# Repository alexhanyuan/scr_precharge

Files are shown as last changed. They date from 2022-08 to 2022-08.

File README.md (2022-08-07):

# scr_precharge
Controller for Solid State Tesla Coil power supply precharging with SCRs. I got tired of welding relays and didn't have the room for larger (>30A) contactors. I had a bunch of Semikron SKKT dual SCR modules, which were the same Semipack 1 style diode modules I was already using. So, using this precharge controller gets rid of the main relay as well as the precharge resistor and relay.

Eagle files for Semipack 1 gate driver boards are also included. These can be soldered up for modules with either gate configuration (GK GK or GK KG). The parts for the spade connectors that work with the Semipack 1 modules are:
https://www.digikey.com/en/products/detail/keystone-electronics/3544/303877

ST Microelectronics has a good app note on controlling SCRs and topologies:
https://www.st.com/resource/en/application_note/an4606-inrushcurrent-limiter-circuits-icl-with-triacs-and-thyristors-scr-and-controlled-bridge-design-tips-stmicroele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

The board comprises of a zero crossing detector, an ATTINY85 which generates the appropriate PWM gate signals, GDT outputs, and opto-isolated control inputs for precharge and run modes. There are two versions of the board, only difference being the type of GDT used, depending on the type of SCR configuration (dual or half SCR/diode modules).

The SCRs will need a gate resistor sized appropriately for the amount of current necessary to turn it on. I used 5.1 ohms on the Semipack 1 SKKT modules. The precharge board outputs must also be phased properly. Additionally, on 120VAC input, the hot line must be connected to pin 1 of X2 otherwise the zero crossing detector will not be able to detect any zero crossings. With 240VAC, both lines are hot so it will not matter.

Pick your opto of choice, then size the resistors according to the logic voltage. I used this with a UD3 so the signals were 24V.

If you have any questions or are looking for a couple of bare boards, feel free to shoot me a message! 

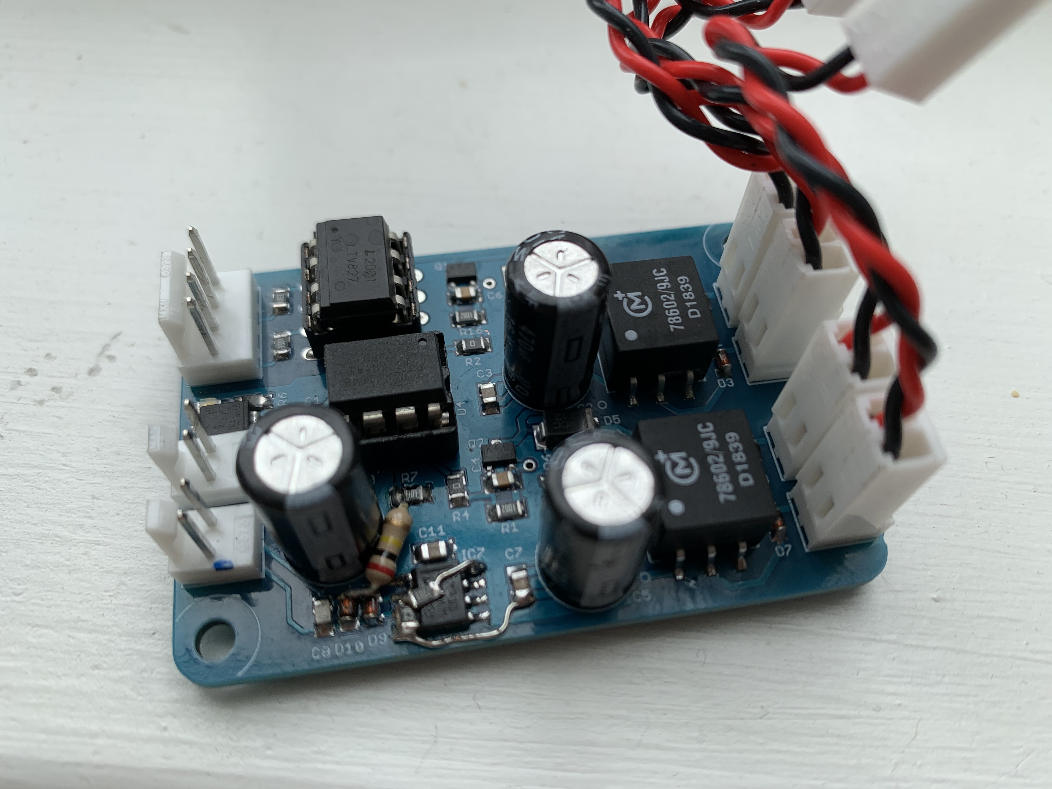
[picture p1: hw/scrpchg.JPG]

|:--:| 
| *Figure 1. Controller board. Note that this is was the original version and modifications needed to be made to the zero crossing detector. These changes are reflected in the latest board files.* |

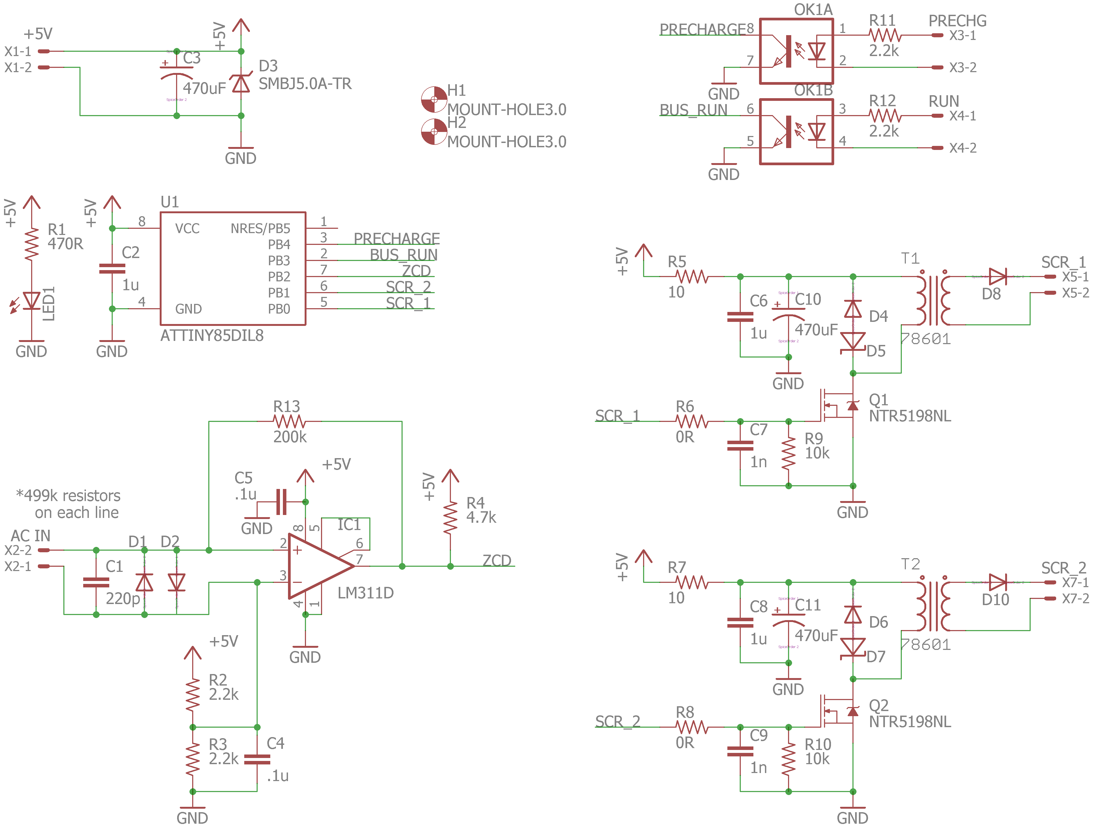
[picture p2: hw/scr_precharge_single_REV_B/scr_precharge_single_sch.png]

|:--:| 
| *Figure 2. Schematic of single output controller board.* |

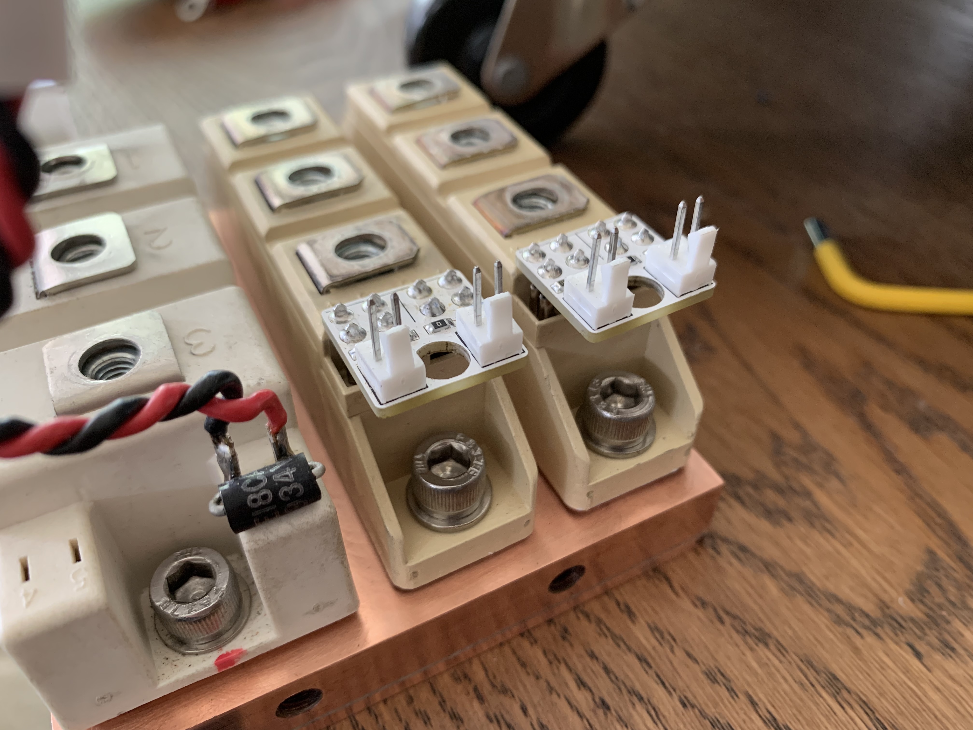
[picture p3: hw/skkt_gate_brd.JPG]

|:--:| 
| *Figure 3. Dual Semikron SCR modules with the gate boards.* |

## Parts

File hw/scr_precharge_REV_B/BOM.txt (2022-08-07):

Partlist

Exported from scr_precharge.sch at 8/6/2022 15:54

EAGLE Version 7.6.0 Copyright (c) 1988-2016 CadSoft

Assembly variant: 

Part     Value           Device             Package      Library               Sheet

C1       220p            C-EUC0805          C0805        resistor              1
C2       1u              C-EUC0805          C0805        resistor              1
C3       470uF           CPOL-USE3.5-8      E3,5-8       resistor              1
C4       .1u             C-EUC0805          C0805        resistor              1
C5       .1u             C-EUC0805          C0805        resistor              1
C6       1u              C-EUC0805          C0805        resistor              1
C7       1n (DNP)        C-EUC0805          C0805        resistor              1
C8       1u              C-EUC0805          C0805        resistor              1
C9       1n (DNP)        C-EUC0805          C0805        resistor              1
C10      470uF           CPOL-USE3.5-8      E3,5-8       resistor              1
C11      470uF           CPOL-USE3.5-8      E3,5-8       resistor              1
D1       1N4148MICROMELF 1N4148MICROMELF    MICROMELF-W  diode                 1
D2       1N4148MICROMELF 1N4148MICROMELF    MICROMELF-W  diode                 1
D3       SMBJ5.0A-TR     SMBJ5.0A-TR        DO214AA      diode                 1
D4       1N4148MICROMELF 1N4148MICROMELF    MICROMELF-W  diode                 1
D5       SMAZ12-TP       SMAZ12-TP          DO-214AC     diode                 1
D6       1N4148MICROMELF 1N4148MICROMELF    MICROMELF-W  diode                 1
D7       SMAZ12-TP       SMAZ12-TP          DO-214AC     diode                 1
D8       1N4148MICROMELF 1N4148MICROMELF    MICROMELF-W  diode                 1
D9       1N4148MICROMELF 1N4148MICROMELF    MICROMELF-W  diode                 1
D10      1N4148MICROMELF 1N4148MICROMELF    MICROMELF-W  diode                 1
D11      1N4148MICROMELF 1N4148MICROMELF    MICROMELF-W  diode                 1
IC1      LM311D          LM311D             SO08         linear                1
LED1                     LEDCHIP-LED0805    CHIP-LED0805 led                   1
OK1      ILD621          ILD621             DIL08        optocoupler           1
Q1       SSM3K341R.LF    MOSFET-NCH-AO3404A SOT23-3      SparkFun-DiscreteSemi 1
Q2       SSM3K341R.LF    MOSFET-NCH-AO3404A SOT23-3      SparkFun-DiscreteSemi 1
R1       470R            R-US_R0805         R0805        resistor              1
R2       2.2k            R-US_R0805         R0805        resistor              1
R3       2.2k            R-US_R0805         R0805        resistor              1
R4       4.7k            R-US_R0805         R0805        resistor              1
R5       10              R-US_R2010         R2010        resistor              1
R6       0R              R-US_R0805         R0805        resistor              1
R7       10              R-US_R2010         R2010        resistor              1
R8       0R              R-US_R0805         R0805        resistor              1
R9       10k             R-US_R0805         R0805        resistor              1
R10      10k             R-US_R0805         R0805        resistor              1
R11      2.2k            R-US_R0805         R0805        resistor              1
R12      2.2k            R-US_R0805         R0805        resistor              1
R13      200k            R-US_R0805         R0805        resistor              1
T1       78602           78602              J-STD-020D   Alex                  1
T2       78602           78602              J-STD-020D   Alex                  1
U1       ATTINY85DIL8    ATTINY85DIL8       DIL8         attiny85              1
X1       +5V             22-23-2021         22-23-2021   con-molex             1
X2       AC IN           22-23-2021         22-23-2021   con-molex             1
X3       PRECHG          22-23-2021         22-23-2021   con-molex             1
X4       RUN             22-23-2021         22-23-2021   con-molex             1
X5       SCR_1A          22-23-2021         22-23-2021   con-molex             1
X6       SCR_2B          22-23-2021         22-23-2021   con-molex             1
X7       SCR_2A          22-23-2021         22-23-2021   con-molex             1
X8       SCR_1B          22-23-2021         22-23-2021   con-molex             1

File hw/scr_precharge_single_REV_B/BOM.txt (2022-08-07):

Partlist

Exported from scr_precharge.sch at 8/6/2022 15:50

EAGLE Version 7.6.0 Copyright (c) 1988-2016 CadSoft

Assembly variant: 

Part     Value           Device             Package      Library               Sheet

C1       220p            C-EUC0805          C0805        resistor              1
C2       1u              C-EUC0805          C0805        resistor              1
C3       470uF           CPOL-USE3.5-8      E3,5-8       resistor              1
C4       .1u             C-EUC0805          C0805        resistor              1
C5       .1u             C-EUC0805          C0805        resistor              1
C6       1u              C-EUC0805          C0805        resistor              1
C7       1n (DNP)        C-EUC0805          C0805        resistor              1
C8       1u              C-EUC0805          C0805        resistor              1
C9       1n (DNP)        C-EUC0805          C0805        resistor              1
C10      470uF           CPOL-USE3.5-8      E3,5-8       resistor              1
C11      470uF           CPOL-USE3.5-8      E3,5-8       resistor              1
D1       1N4148MICROMELF 1N4148MICROMELF    MICROMELF-W  diode                 1
D2       1N4148MICROMELF 1N4148MICROMELF    MICROMELF-W  diode                 1
D3       SMBJ5.0A-TR     SMBJ5.0A-TR        DO214AA      diode                 1
D4       1N4148MICROMELF 1N4148MICROMELF    MICROMELF-W  diode                 1
D5       SMAZ12-TP       SMAZ12-TP          DO-214AC     diode                 1
D6       1N4148MICROMELF 1N4148MICROMELF    MICROMELF-W  diode                 1
D7       SMAZ12-TP       SMAZ12-TP          DO-214AC     diode                 1
D8       1N4148MICROMELF 1N4148MICROMELF    MICROMELF-W  diode                 1
D10      1N4148MICROMELF 1N4148MICROMELF    MICROMELF-W  diode                 1
IC1      LM311D          LM311D             SO08         linear                1
LED1                     LEDCHIP-LED0805    CHIP-LED0805 led                   1
OK1      ILD621          ILD621             DIL08        optocoupler           1
Q1       SSM3K341R.LF    MOSFET-NCH-AO3404A SOT23-3      SparkFun-DiscreteSemi 1
Q2       SSM3K341R.LF    MOSFET-NCH-AO3404A SOT23-3      SparkFun-DiscreteSemi 1
R1       470R            R-US_R0805         R0805        resistor              1
R2       2.2k            R-US_R0805         R0805        resistor              1
R3       2.2k            R-US_R0805         R0805        resistor              1
R4       4.7k            R-US_R0805         R0805        resistor              1
R5       10              R-US_R2010         R2010        resistor              1
R6       0R              R-US_R0805         R0805        resistor              1
R7       10              R-US_R2010         R2010        resistor              1
R8       0R              R-US_R0805         R0805        resistor              1
R9       10k             R-US_R0805         R0805        resistor              1
R10      10k             R-US_R0805         R0805        resistor              1
R11      2.2k            R-US_R0805         R0805        resistor              1
R12      2.2k            R-US_R0805         R0805        resistor              1
R13      200k            R-US_R0805         R0805        resistor              1
T1       78601           78601              J-STD-020D   Alex                  1
T2       78601           78601              J-STD-020D   Alex                  1
U1       ATTINY85DIL8    ATTINY85DIL8       DIL8         attiny85              1
X1       +5V             22-23-2021         22-23-2021   con-molex             1
X2       AC IN           22-23-2021         22-23-2021   con-molex             1
X3       PRECHG          22-23-2021         22-23-2021   con-molex             1
X4       RUN             22-23-2021         22-23-2021   con-molex             1
X5       SCR_1           22-23-2021         22-23-2021   con-molex             1
X7       SCR_2           22-23-2021         22-23-2021   con-molex             1

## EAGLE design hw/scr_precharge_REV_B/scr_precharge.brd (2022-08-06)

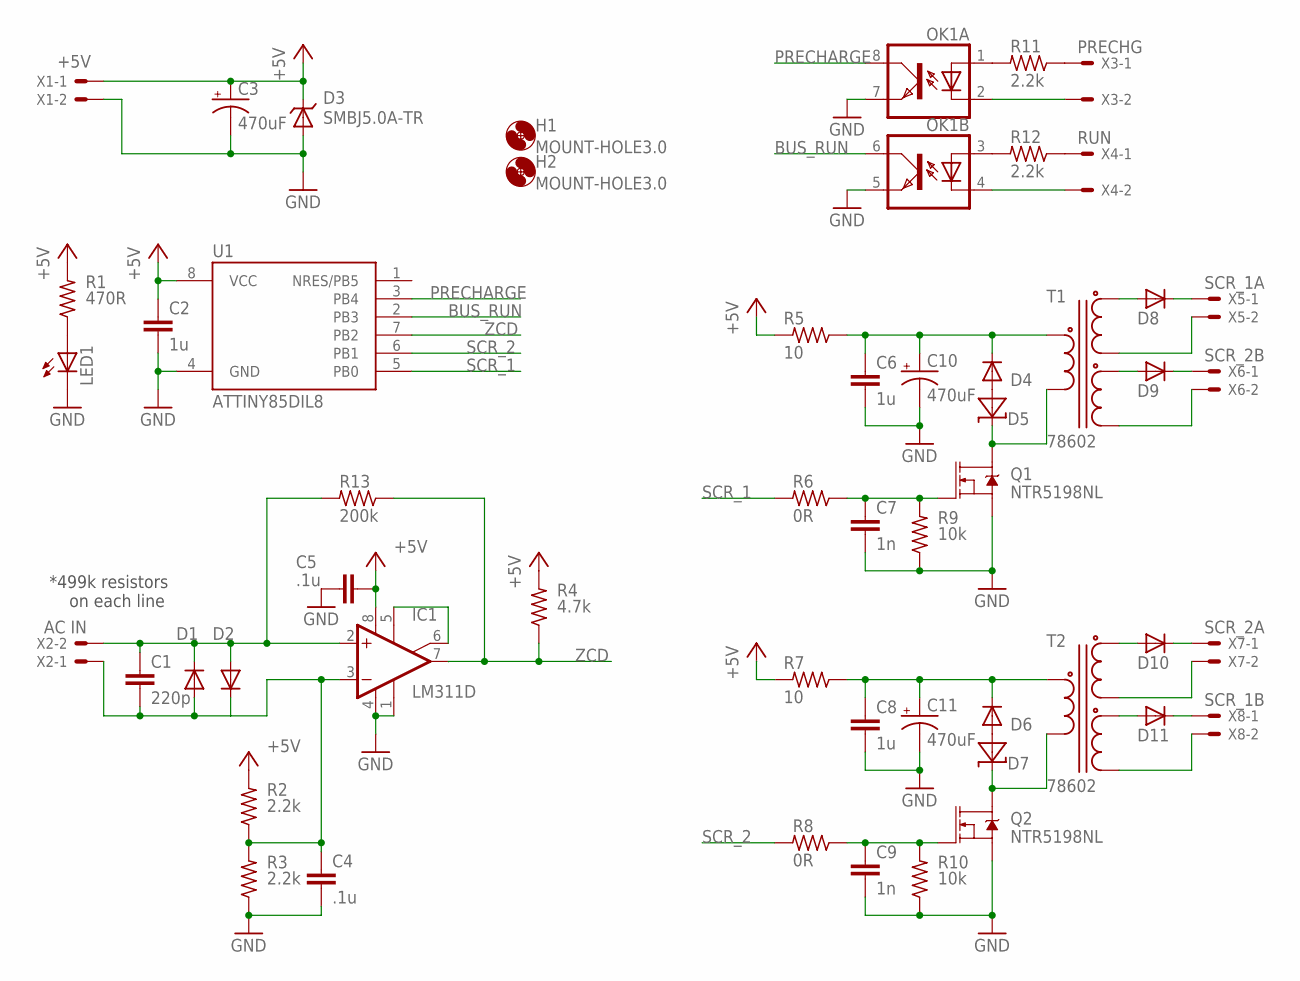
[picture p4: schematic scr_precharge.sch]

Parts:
C1: 220p; C0805
C2, C6, C8: 1u; C0805
C3, C10, C11: 470uF; E3,5-8
C4, C5: .1u; C0805
C7, C9: 1n; C0805
D1, D2, D4, D6, D8, D9, D10, D11: 1N4148MICROMELF; MICROMELF-W
D3: SMBJ5.0A-TR; DO214AA
D5, D7: SMAZ12-TP; DO-214AC
H1, H2: MOUNT-HOLE3.0; 3,0
IC1: LM311D; SO08
LED1: LEDCHIP-LED0805; CHIP-LED0805
OK1: ILD621; DIL08
Q1, Q2: NTR5198NL; SOT23-3
R1: 470R; R0805
R2, R3, R11, R12: 2.2k; R0805
R4: 4.7k; R0805
R5, R7: 10; R2010
R6, R8: 0R; R0805
R9, R10: 10k; R0805
R13: 200k; R0805
T1, T2: 78602; J-STD-020D
U1: ATTINY85DIL8; DIL8
X1: +5V; 22-23-2021
X2: AC IN; 22-23-2021
X3: PRECHG; 22-23-2021
X4: RUN; 22-23-2021
X5: SCR_1A; 22-23-2021
X6: SCR_2B; 22-23-2021
X7: SCR_2A; 22-23-2021
X8: SCR_1B; 22-23-2021

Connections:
+5V: C2.1, C3.+, C5.2, D3.C, IC1.8 (V+), R1.2, R2.2, R4.2, R5.2, R7.2, U1.8 (VCC), X1.1
BUS_RUN: OK1.6 (COL), U1.2 (PB3)
GND: C2.2, C3.-, C4.2, C5.1, C6.2, C7.2, C8.2, C9.2, C10.-, C11.-, D3.A, IC1.1 (GND), IC1.4 (V-), LED1.C, OK1.5 (EMIT), OK1.7 (EMIT), Q1.2 (S), Q2.2 (S), R3.1, R9.1, R10.1, U1.4 (GND), X1.2
unnamed: OK1.1 (A), R11.2
unnamed: D4.A, D5.A
unnamed: C6.1, C10.+, D4.C, R5.1, T1.P$1
unnamed: D8.A, T1.P$2
unnamed: D5.C, Q1.3 (D), T1.P$6
unnamed: D8.C, X5.1
unnamed: T1.P$5, X5.2
unnamed: T1.P$4, X6.2
unnamed: D9.C, X6.1
unnamed: D9.A, T1.P$3
unnamed: C8.1, C11.+, D6.C, R7.1, T2.P$1
unnamed: D7.C, Q2.3 (D), T2.P$6
unnamed: D6.A, D7.A
unnamed: D10.A, T2.P$2
unnamed: D10.C, X7.1
unnamed: T2.P$5, X7.2
unnamed: T2.P$4, X8.2
unnamed: D11.C, X8.1
unnamed: D11.A, T2.P$3
unnamed: C1.1, D1.C, D2.A, IC1.2 (+IN), R13.2, X2.2
unnamed: LED1.A, R1.1
unnamed: OK1.3 (A), R12.2
unnamed: R12.1, X4.1
unnamed: R11.1, X3.1
unnamed: OK1.4 (C), X4.2
unnamed: OK1.2 (C), X3.2
unnamed: C7.1, Q1.1 (G), R6.1, R9.2
unnamed: C9.1, Q2.1 (G), R8.1, R10.2
unnamed: C1.2, C4.1, D1.A, D2.C, IC1.3 (-IN), R2.1, R3.2, X2.1
unnamed: IC1.5 (ON), IC1.6 (ON/STR)
PRECHARGE: OK1.8 (COL), U1.3 (PB4)
SCR_1: R6.2, U1.5 (PB0)
SCR_2: R8.2, U1.6 (PB1)
ZCD: IC1.7 (OUT), R4.1, R13.1, U1.7 (PB2)

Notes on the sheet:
*499k resistors on each line

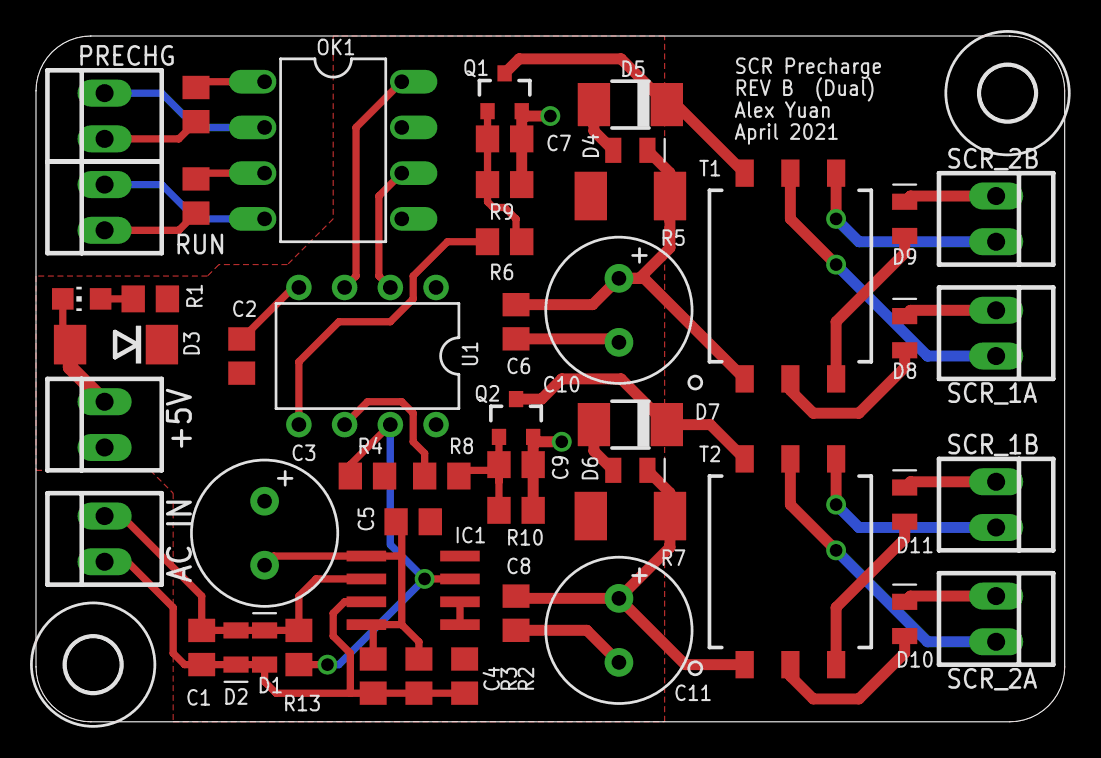
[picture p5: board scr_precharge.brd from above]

Board: 2 copper layers, 57.1 x 38.1 mm, 53 parts (0 on the bottom side), 37 nets.

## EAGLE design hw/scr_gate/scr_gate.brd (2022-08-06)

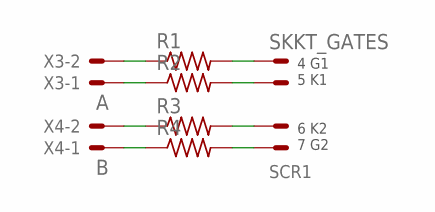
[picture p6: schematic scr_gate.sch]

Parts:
R1, R2, R3, R4: R-US_M0805; M0805
SCR1: SKKT_GATES
X3: A; 22-23-2021
X4: B; 22-23-2021

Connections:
unnamed: R3.2, SCR1.P$3 (3), SCR1.P$7 (3)
unnamed: R1.2, SCR1.P$1 (1), SCR1.P$5 (1)
unnamed: R2.2, SCR1.P$2 (2), SCR1.P$6 (2)
unnamed: R2.1, X3.1
unnamed: R4.2, SCR1.P$4 (4), SCR1.P$8 (4)
unnamed: R1.1, X3.2
unnamed: R4.1, X4.1
unnamed: R3.1, X4.2

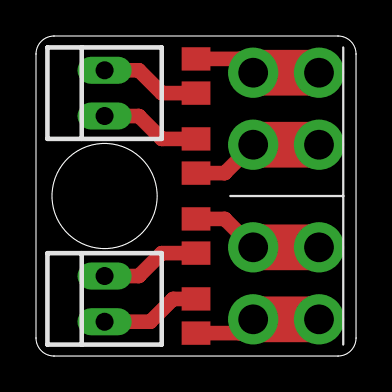
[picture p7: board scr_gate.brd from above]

Board: 2 copper layers, 17.8 x 17.8 mm, 7 parts (0 on the bottom side), 8 nets.

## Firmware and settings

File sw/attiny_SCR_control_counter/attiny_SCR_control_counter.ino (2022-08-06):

// SCR precharge code for attiny
// 210711
// change digitalRead and digitalWrites to direct register access in final code revision

#define precharge 4     // precharge input pin
#define bus_run   3     // bus_run input pin
#define SCR_1     0     // SCR 1 output pin
#define SCR_2     1     // SCR 2 output pin
#define timeout   123   // max TCNT1 value before it shuts off PWM outputs, this should kick in right before the next 60Hz half cycle
#define precharge_speed 3000 // adjusts precharge speed, larger = longer time, slower precharge

byte ZC = 0;            // zero crossing status
byte charge_status = 0; // 0 = off, 1 = charging, 2 = run, 3 = precharge -> run
bool bus_run_condition = 0;
bool precharge_condition = 0;
int alpha = 0;          // delay iterator

void setup(void) {
  pinMode(precharge, INPUT_PULLUP);  // precharge, active high
  pinMode(bus_run,   INPUT_PULLUP);  // run, active high
  pinMode(SCR_1, OUTPUT);    // SCR trigger 1, these probably don't need to be defined, but i'm just making sure
  pinMode(SCR_2, OUTPUT);    // SCR trigger 2
  digitalWrite(SCR_1, LOW);  // ensure digital outputs are LOW
  digitalWrite(SCR_2, LOW);  // ensure digital outputs are LOW
  
  // SCR pulsing PWM configuration
  OCR0A = 80;           // set PWM1 duty cycle (about 50µs pulse, pin 9)
  OCR0B = 80;           // set PWM2 duty cycle (about 50µs pulse, pin 10)
  TCCR0B = 0b00000001;  // set Timer1 clock to CLKio/8 (get PWM frequency of 3.9375 kHz)
  TCCR0A =  0;          // ensure SCR outputs are off
  
  // counter configuration
  TCCR1 = 0b00001010;   // CLKio/512 prescaler
  OCR1A = timeout-2;    // delay before turning on SCRs for precharge
  OCR1B = timeout;      // shut off SCRs, this is about how long a 60Hz half cycle period is, minus a slight margin
  GTCCR = 0;            // make sure everything here is disabled!!!!!!!!!!!!!!!!!
  TIMSK = 0b00100000;   // enable OCM B INT, B acts as a timeout and shuts off SCRs

  attachInterrupt(0, ZC_detect, CHANGE);  // enable INT0 for ZCD
}

void ZC_detect() { // ISR to handle zero crossing event  
  TCCR0A =  0; // turn off SCRs, though they should be off at this point already due to the timeout ISR
  
  if(digitalRead(2)) ZC = 1; // determines polarity of AC cycle
  else ZC = 2;

  TCNT0 = 0; // this reduces overal jitter of the SCR PWM
  TCNT1 = 0; // reset counter

  if(charge_status == 2) { // having this here reduces some jitter when PWM first starts in the cycle
    TCCR0A = (ZC == 1) ? 0x81 : 0x21; // enable SCRs based on AC polarity
    ZC = 0; // this for loop doesn't need to be accessed till the next 60Hz half cycle
  }
}

void loop() {
  bus_run_condition = !digitalRead(bus_run);
  precharge_condition = !digitalRead(precharge);

//  if(bus_run_condition && !precharge_condition) { // active low, if bus_run and not precharging // add && precharge_done maybe for soft transistion to run
//  if(bus_run_condition && precharge_condition && (charge_status == 1)) { // To run, UD3 enables both of these. Check that it came from precharge status.
  if(bus_run_condition && precharge_condition) {
    if(charge_status != 2) {
      charge_status = 2; // it is now in run mode
      TIMSK = TIMSK & 0b10111111; // unenable OCM A INT
    }
  }
    
  else if(!bus_run_condition && precharge_condition) { // precharging
    if(charge_status == 0) {
      charge_status = 1;    // it is now in charging mode
      OCR1A = timeout-2;    // reset charging progress
      alpha = 0;            // reset delay iterator
    }
    
    if(charge_status == 1) {
      TIMSK = TIMSK | 0b01000000; // enable OCM A INT

      if(alpha >= precharge_speed) {  // decrement OCR0A at precharge speed rate
        OCR1A -= 1;                   // turn on SCR earlier
        if(OCR1A <= 60) OCR1A = 60;   // limit earliest turn on to about 97 degrees (only needs to go to 90 degrees for max voltage)
        alpha = 0;                    // reset delay iterator
      }
      else alpha++;                   // increment delay iterator
    }
  }

  else { // neither, shut everything off                                          if(!bus_run_condition && !precharge_condition) {
    charge_status = 0;                // not trying to charge or run
    TIMSK = TIMSK & 0b10111111;       // unenable OCM A INT

//    TCCR1A =  0; // turn off everything. enabling this immediately turns off the output, disabling turns off the output on the next ZCD
  }
}

ISR(TIMER1_COMPA_vect) { // timer 1 interrupt
  if(TCNT1 > OCR1A) { // this prevents the initial full pulse before precharging, which is bad
    TCCR0A = ((ZC == 1) && (ZC != 0)) ? 0x81 : 0x21; // enable SCRs based on AC polarity  ********************** check for ZC = 2 maybe? <<kinda done
  }
}

ISR(TIMER1_COMPB_vect) { // timer 1 interrupt
  TCCR0A =  0; // timeout, shut SCRs off before start of next 60Hz half cycle
}

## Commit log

2022-08-06 adding photo of skkt gate board
2022-08-06 added BOMs
    [scr_precharge.sch]

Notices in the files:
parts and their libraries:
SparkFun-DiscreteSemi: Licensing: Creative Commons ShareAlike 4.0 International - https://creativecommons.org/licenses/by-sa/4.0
